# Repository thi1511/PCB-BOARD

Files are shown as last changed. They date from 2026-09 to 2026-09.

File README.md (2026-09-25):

# STM32WB55 RF Development Board

## 📌 Giới thiệu

Đây là thiết kế một board phát triển sử dụng vi điều khiển **STM32WB55CEU6**, được thiết kế và layout bằng **KiCad**.

Board tích hợp các khối nguồn 3.3V, USB-C, UART, SWD, BOOT/RESET, mạch dao động và khối RF Front-End với đầu nối RF coaxial.

---

## 🧩 Thành phần chính

- **MCU:** STM32WB55CEU6
- **Nguồn vào:** USB-C 5V
- **Nguồn hệ thống:** +3.3V
- **LDO:** MIC5365-3.3YD5
- **USB:** USB Type-C
- **Debug/Programming:** SWD Header
- **UART:** UART Header
- **RF Front-End:** DLF162500LT-502BA1
- **RF Connector:** Coaxial RF Connector
- **High-Speed Crystal:** 32 MHz
- **Low-Speed Crystal:** 32.768 kHz
- **BOOT:** BOOT0 Push Button
- **RESET:** NRST
- **LED:** Status LED

---

## 🔌 Các giao tiếp

### USB-C

USB-C được sử dụng để cấp nguồn và kết nối với board.

### UART

UART Header được sử dụng để giao tiếp UART với vi điều khiển.

### SWD

SWD Header hỗ trợ:

- Nạp firmware
- Debug chương trình
- Kết nối ST-LINK

### RF

Khối RF được kết nối từ STM32WB55CEU6 đến RF Front-End và đầu nối coaxial.

---

## ⚡ Khối nguồn

Nguồn **5V từ USB-C** được đưa qua IC **MIC5365-3.3YD5** để tạo nguồn **+3.3V** cho hệ thống.

Các tụ bypass và decoupling được bố trí xung quanh MCU và các khối nguồn nhằm đảm bảo nguồn hoạt động ổn định.

---

## ⏱️ Clock

Board sử dụng hai nguồn clock:

- **32 MHz crystal:** High-Speed External Clock
- **32.768 kHz crystal:** Low-Speed External Clock

---

## 🎛️ BOOT & RESET

Board được tích hợp:

- **BOOT0 Push Button:** lựa chọn chế độ boot
- **NRST:** reset MCU

---

## 📐 PCB Design

PCB được thiết kế bằng **KiCad**.

### PCB Layout

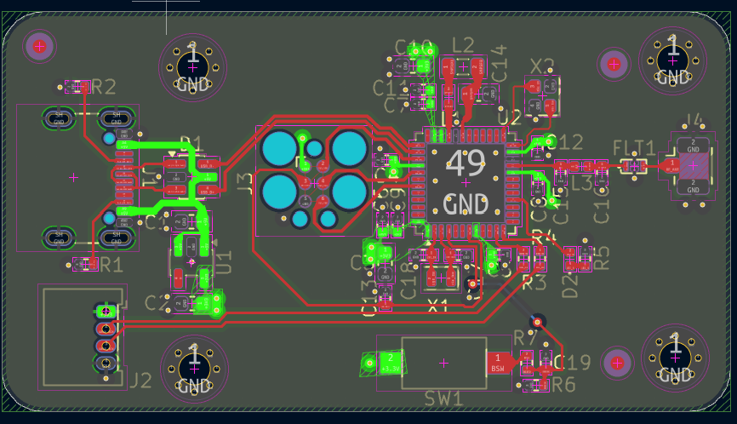
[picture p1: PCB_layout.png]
PCB Layout


### PCB 3D View

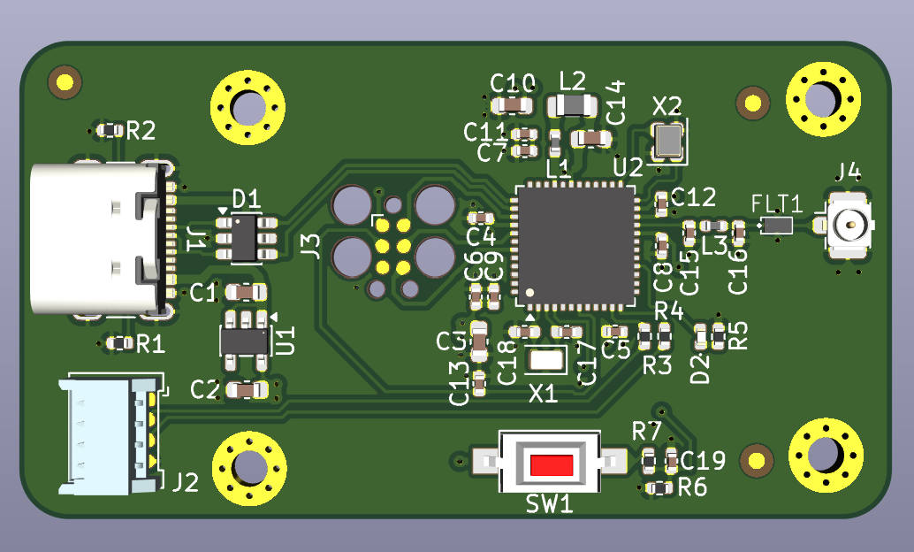
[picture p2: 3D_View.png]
PCB 3D View


---

## 🖥️ Schematic

Sơ đồ nguyên lý của board:

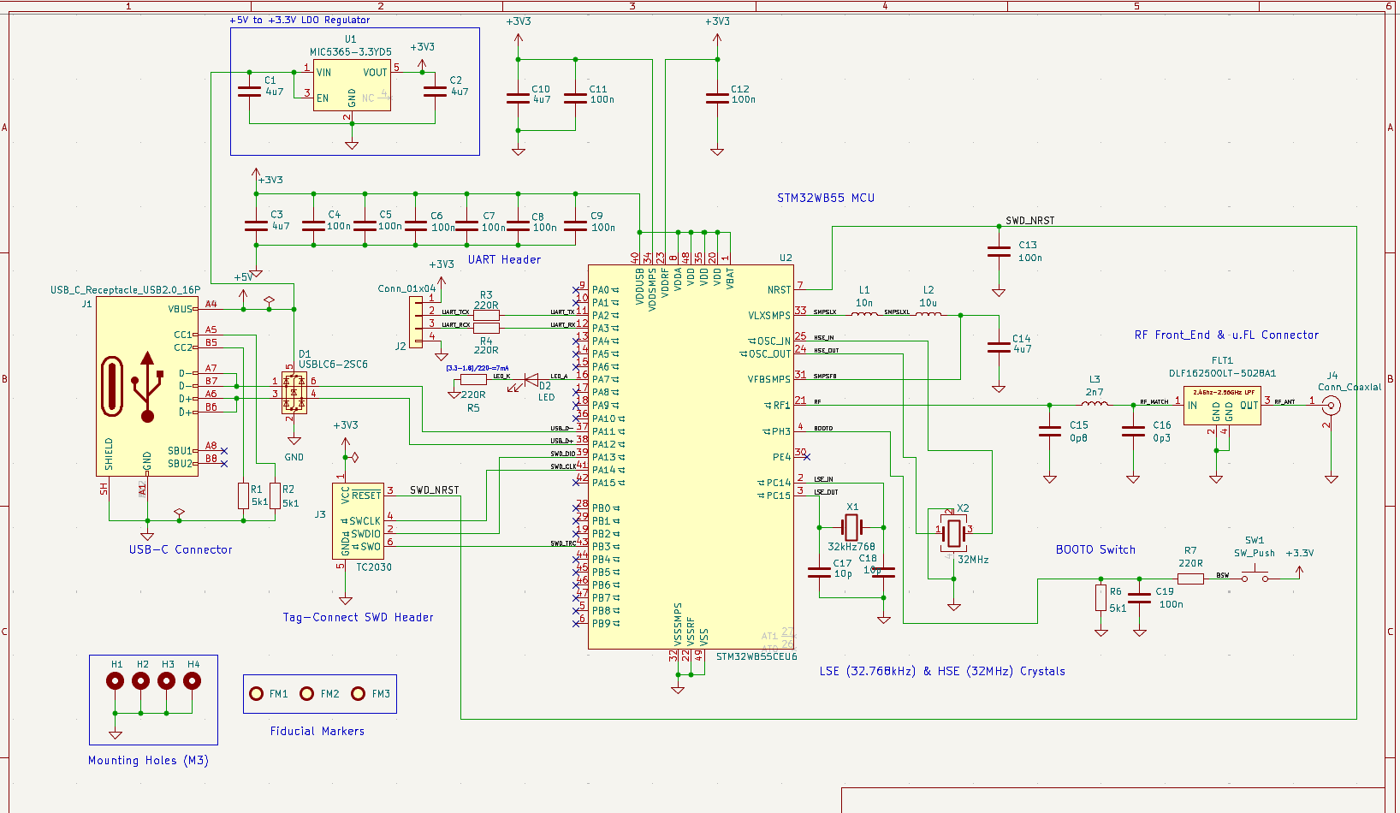
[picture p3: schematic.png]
Schematic


---

## 📁 Cấu trúc thư mục

```text
STM32WB55-RF-Board/
│
├── README.md
│
├── Schematic/
│   └── STM32WB55.kicad_sch
│
├── PCB/
│   ├── STM32WB55.kicad_pcb
│   └── Gerber/
│
├── Images/
│   ├── schematic.png
│   ├── pcb_layout.png
│   └── pcb_3d.png
│
├── 3D_Models/
│   └── ...
│
└── Libraries/
    └── ...

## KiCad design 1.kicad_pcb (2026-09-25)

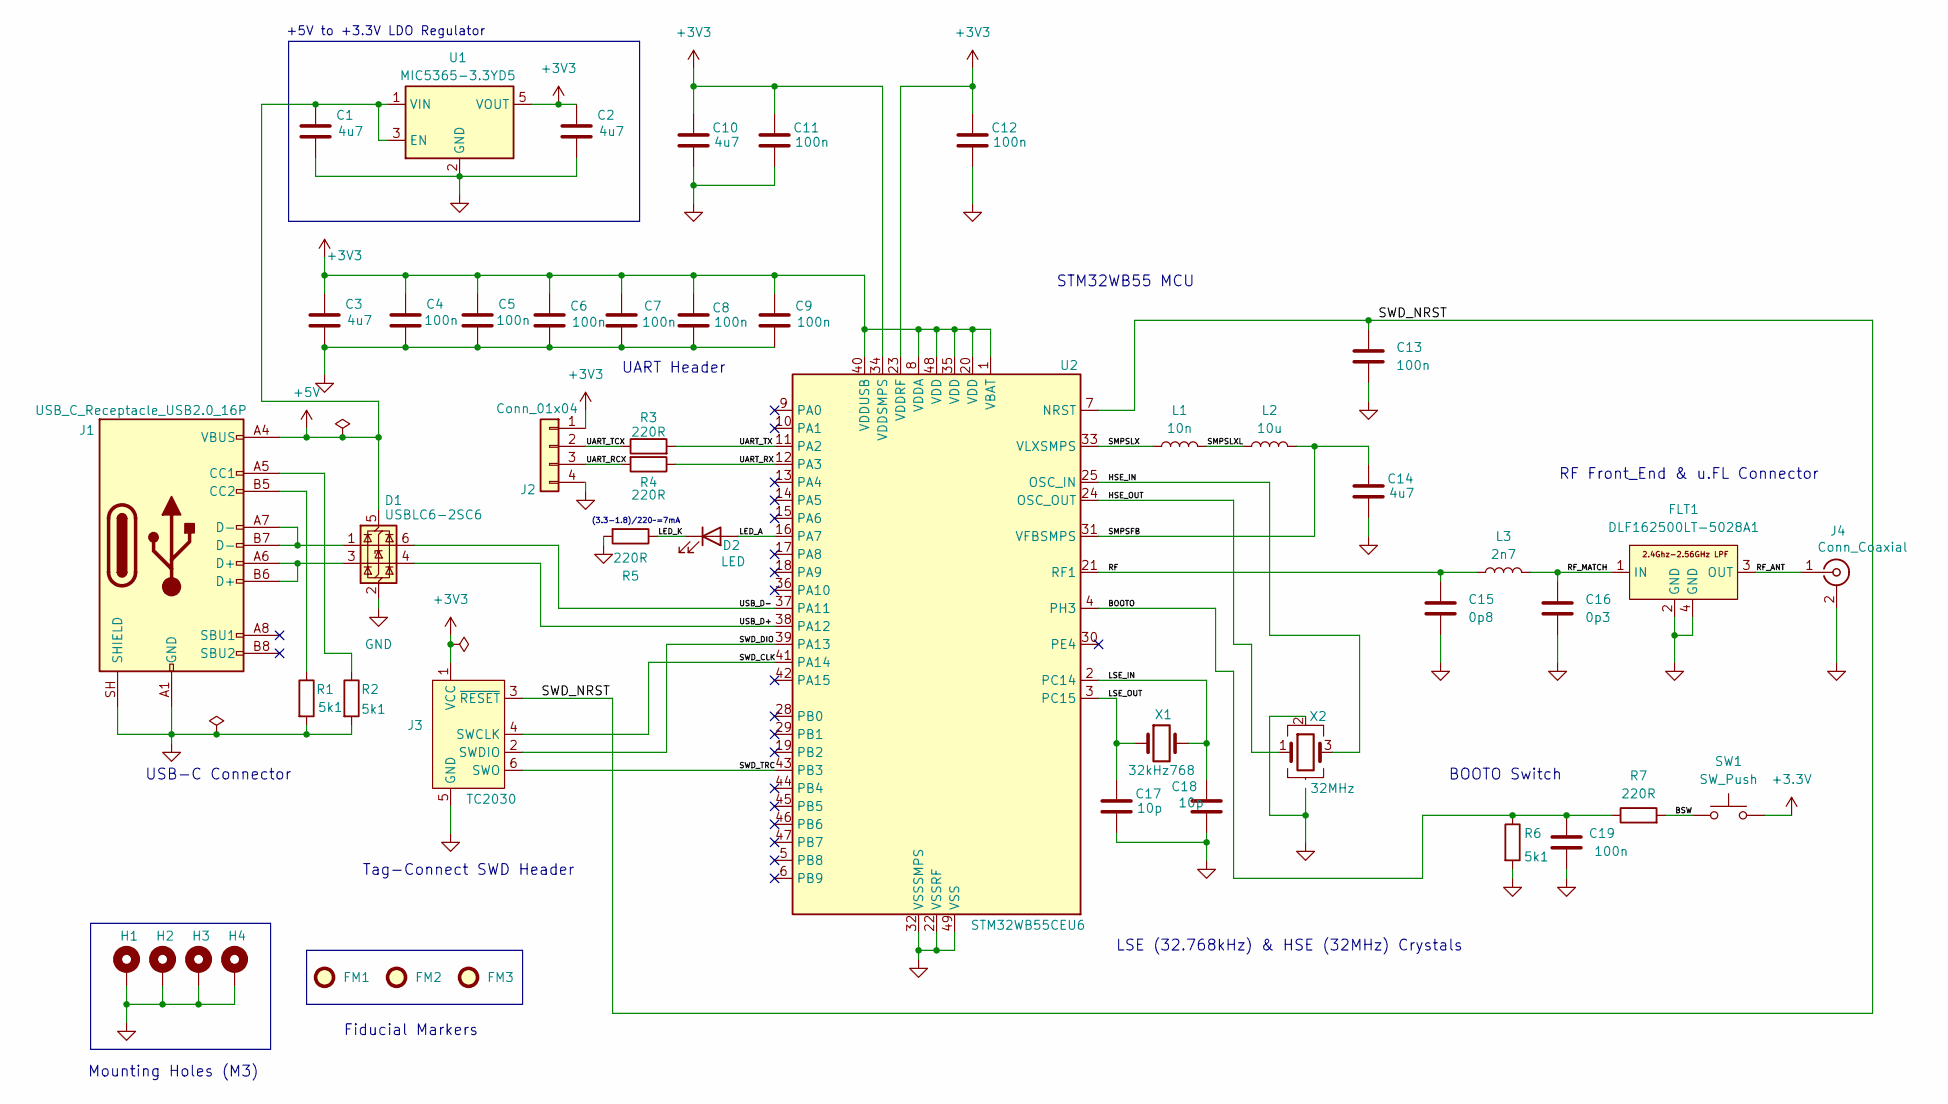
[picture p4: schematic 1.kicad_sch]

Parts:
C1, C2, C3, C10, C14: 4u7; C_0603_1608Metric
C4, C5, C6, C7, C8, C9, C11, C12, C13, C19: 100n; C_0402_1005Metric
C15: 0p8; C_0402_1005Metric
C16: 0p3; C_0402_1005Metric
C17, C18: 10p; C_0402_1005Metric_Pad0.74x0.62mm_HandSolder
D1: USBLC6-2SC6; SOT-23-6
D2: LED; LED_0402_1005Metric
FLT1: DLF162500LT-5028A1
FM1, FM2, FM3: Fiducial; Fiducial_1mm_Mask2mm
H1, H2, H3, H4: MountingHole_Pad; MountingHole_2.2mm_M2_Pad_Via
J1: USB_C_Receptacle_USB2.0_16P; USB_C_Receptacle_GCT_USB4105-xx-A_16P_TopMnt_Horizontal
J2: Conn_01x04; Molex_PicoBlade_53048-0410_1x04_P1.25mm_Horizontal
J3: TC2030; Tag-Connect_TC2030-IDC-FP_2x03_P1.27mm_Vertical
J4: Conn_Coaxial; U.FL_Hirose_U.FL-R-SMT-1_Vertical
L1: 10n; L_0402_1005Metric
L2: 10u; L_0805_2012Metric
L3: 2n7; L_0402_1005Metric
R1, R2, R6: 5k1; R_0402_1005Metric
R3, R4, R5, R7: 220R; R_0402_1005Metric
SW1: SW_Push; SW_SPST_CK_RS282G05A3
U1: MIC5365-3.3YD5; TSOT-23-5
U2: STM32WB55CEU6; QFN-48-1EP_7x7mm_P0.5mm_EP5.6x5.6mm
X1: 32kHz768; Crystal_SMD_2012-2Pin_2.0x1.2mm
X2: 32MHz

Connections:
+3.3V: SW1.2
+3V3: C2.1, C3.1, C4.1, C5.1, C6.1, C7.1, C8.1, C9.1, C10.1, C11.1, C12.1, J2.1, J3.1 (VCC), U1.5 (VOUT), U2.1 (VBAT), U2.8 (VDDA), U2.20 (VDD), U2.23 (VDDRF), U2.34 (VDDSMPS), U2.35 (VDD), U2.40 (VDDUSB), U2.48 (VDD)
+5V: C1.1, D1.5 (VBUS), J1.A4 (VBUS), J1.A9 (VBUS), J1.B4 (VBUS), J1.B9 (VBUS), U1.1 (VIN), U1.3 (EN)
/BOOTO: C19.1, R6.1, R7.1, U2.4 (PH3)
/BSW: R7.2, SW1.1
/HSE_IN: U2.25 (OSC_IN), X2.3
/HSE_OUT: U2.24 (OSC_OUT), X2.1
/LED_A: D2.2 (A), U2.16 (PA7)
/LED_K: D2.1 (K), R5.1
/LSE_IN: C18.1, U2.2 (PC14), X1.2
/LSE_OUT: C17.1, U2.3 (PC15), X1.1
/RF: C15.1, L3.1, U2.21 (RF1)
/RF_ANT: FLT1.3 (OUT), J4.1 (In)
/RF_MATCH: C16.1, FLT1.1 (IN), L3.2
/SMPSFB: C14.1, L2.2, U2.31 (VFBSMPS)
/SMPSLX: L1.1, U2.33 (VLXSMPS)
/SMPSLXL: L1.2, L2.1
/SWD_CLK: J3.4 (SWCLK), U2.41 (PA14)
/SWD_DIO: J3.2 (SWDIO), U2.39 (PA13)
/SWD_NRST: C13.1, J3.3 (~RESET), U2.7 (NRST)
/SWD_TRC: J3.6 (SWO), U2.43 (PB3)
/UART_RCX: J2.3, R4.2
/UART_RX: R4.1, U2.12 (PA3)
/UART_TCX: J2.2, R3.1
/UART_TX: R3.2, U2.11 (PA2)
/USB_D+: D1.4 (I/O2), U2.38 (PA12)
/USB_D-: D1.6 (I/O1), U2.37 (PA11)
unnamed: D1.1 (I/O1), J1.A7 (D-), J1.B7 (D-)
unnamed: D1.3 (I/O2), J1.A6 (D+), J1.B6 (D+)
unnamed: J1.A5 (CC1), R2.1
unnamed: J1.B5 (CC2), R1.1

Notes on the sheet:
Mounting Holes (M3)
BOOTO Switch
LSE (32.768kHz) & HSE (32MHz) Crystals
STM32WB55 MCU
RF Front_End & u.FL Connector
Tag-Connect SWD Header
(3.3-1.8)/220~=7mA
USB-C Connector
+5V to +3.3V LDO Regulator
Fiducial Markers
UART Header

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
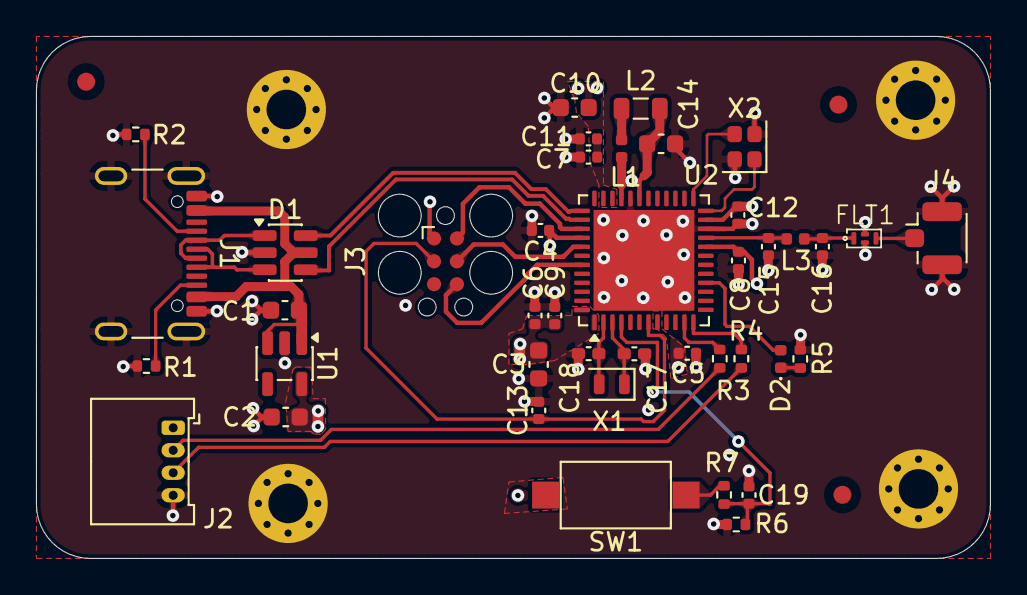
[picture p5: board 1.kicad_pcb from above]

Board: 4 copper layers, 53.0 x 29.0 mm, 48 parts (0 on the bottom side), 31 nets.
